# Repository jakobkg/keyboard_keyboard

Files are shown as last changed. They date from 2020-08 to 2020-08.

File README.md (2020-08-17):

# The Keyboard Keyboard

A mechanical keyboard with a piano-esque layout, or a MIDI keyboard with MX style switches and (hopefully) QMK firmware?
This is a keyboard design for the very tiny segment of people who think the "computer keyboard as MIDI input" in Ableton is neat, and want more of the same.

PCB design is currently ready for prototyping and hopefully writing firmware, and a basic 3D printed case design will also be added to this repository at some point.
Design files and images will be added as they're ready!

## Firmware
I have been able to make a working firmware with remappable MIDI CC knobs, remappable mod keys, a velocity knob and octave controls.
Analog control of velocity is not currently supported in QMK because of the way it handles velocity in the underlying processing, which I have tried to address with [this pull request](https://github.com/qmk/qmk_firmware/pull/9940). If my changes are merged I will be able to provide firmware through the normal QMK repo, if not I will link my own fork here.

## Images

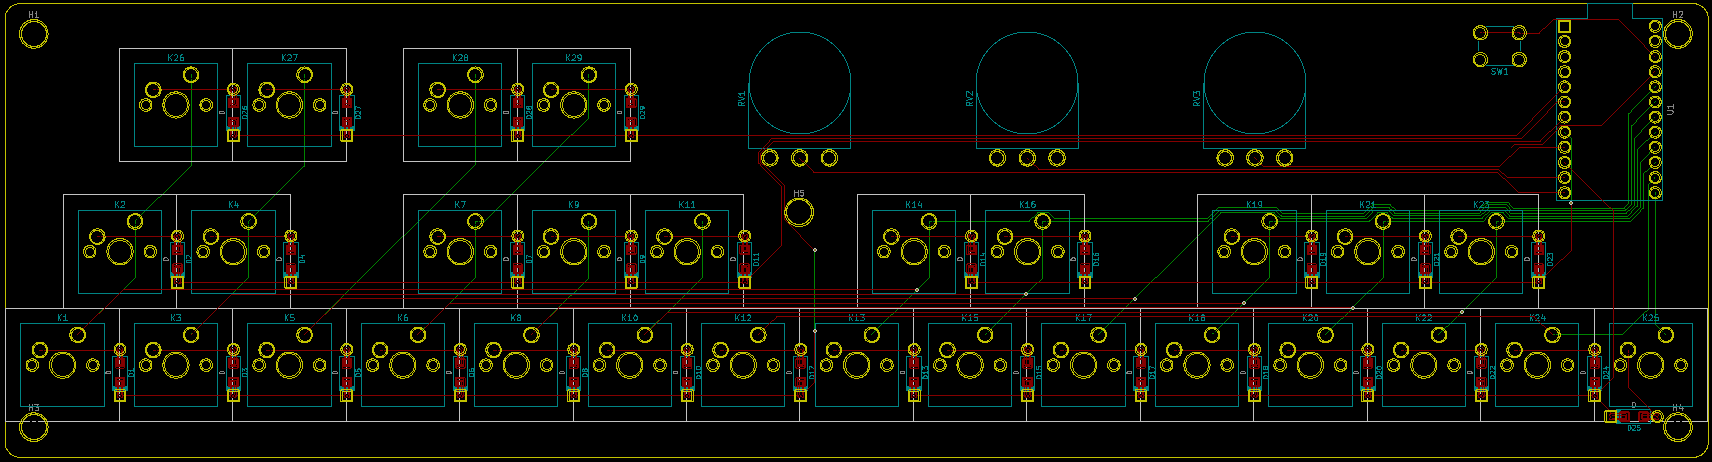
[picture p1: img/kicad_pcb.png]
KiCad screenshot of current PCB design


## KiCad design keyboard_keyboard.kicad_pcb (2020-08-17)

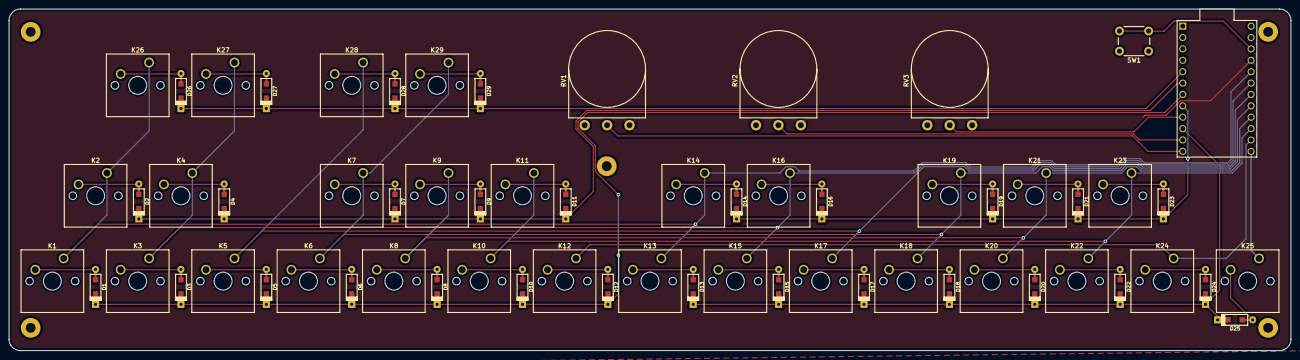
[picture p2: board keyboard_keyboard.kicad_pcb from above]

Board: 2 copper layers, 286.0 x 76.2 mm, 68 parts (0 on the bottom side), 48 nets.

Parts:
D1, D2, D3, D4, D5, D6, D7, D8, D9, D10, D11, D12, D13, D14, D15, D16, D17, D18, D19, D20, D21, D22, D23, D24, D25, D26, D27, D28, D29: D; D_SOD123_axial
H1, H2, H3, H4, H5: MountingHole; MountingHole_2.2mm_M2_Pad
K1, K2, K3, K4, K5, K6, K7, K8, K9, K10, K11, K12, K13, K14, K15, K16, K17, K18, K19, K20, K21, K22, K23, K24, K25, K26, K27, K28, K29: KEYSW; SW_Cherry_MX_1.00u_PCB
RV1, RV2, RV3: R_POT; Potentiometer_Omeg_PC16BU_Vertical
SW1: SW_PUSH; SW_PUSH_6mm
U1: ProMicro

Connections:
Col1: K1.1, K2.1, K13.1, K14.1, K26.1, U1.20
Col2: K3.1, K4.1, K15.1, K16.1, K27.1, U1.19
Col3: K5.1, K17.1, K28.1, U1.18
Col4: K6.1, K7.1, K18.1, K19.1, K29.1, U1.17
Col5: K8.1, K9.1, K20.1, K21.1, U1.16
Col6: K10.1, K11.1, K22.1, K23.1, U1.15
Col7: K12.1, K24.1, U1.14
Col8: K25.1, U1.13
GND: RV1.3, RV2.3, RV3.3, SW1.1, U1.3, U1.4, U1.23
ModRow: D26.1, D27.1, D28.1, D29.1, U1.5
unnamed: D1.2, K1.2
unnamed: D2.2, K2.2
unnamed: D3.2, K3.2
unnamed: D4.2, K4.2
unnamed: D5.2, K5.2
unnamed: D6.2, K6.2
unnamed: D7.2, K7.2
unnamed: D8.2, K8.2
unnamed: D9.2, K9.2
unnamed: D10.2, K10.2
unnamed: D11.2, K11.2
unnamed: D12.2, K12.2
unnamed: D13.2, K13.2
unnamed: D14.2, K14.2
unnamed: D15.2, K15.2
unnamed: D16.2, K16.2
unnamed: D17.2, K17.2
unnamed: D18.2, K18.2
unnamed: D19.2, K19.2
unnamed: D20.2, K20.2
unnamed: D21.2, K21.2
unnamed: D22.2, K22.2
unnamed: D23.2, K23.2
unnamed: D24.2, K24.2
unnamed: D25.2, K25.2
unnamed: D26.2, K26.2
unnamed: D27.2, K27.2
unnamed: D28.2, K28.2
unnamed: D29.2, K29.2
Pot1: RV1.2, U1.12
Pot2: RV2.2, U1.11
Pot3: RV3.2, U1.9
RESET: SW1.2, U1.22
Row1: D2.1, D4.1, D7.1, D9.1, D11.1, U1.6
Row2: D1.1, D3.1, D5.1, D6.1, D8.1, D10.1, D12.1, U1.7
Row3: D14.1, D16.1, D19.1, D21.1, D23.1, U1.8
Row4: D13.1, D15.1, D17.1, D18.1, D20.1, D22.1, D24.1, D25.1, U1.10
VCC: RV1.1, RV2.1, RV3.1, U1.21

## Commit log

2020-07-16 Initial readme and PCB image
2020-08-17 Second iteration of design
    Still based on the pro micro, but smaller PCB with more knobs and mod keys!
    [keyboard_keyboard.kicad_pcb, keyboard_keyboard.sch]
2020-08-17 Remove gerber files from repo
    [keyboard_keyboard-B_Cu.gbr, keyboard_keyboard-B_Mask.gbr, keyboard_keyboard-B_Paste.gbr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]
